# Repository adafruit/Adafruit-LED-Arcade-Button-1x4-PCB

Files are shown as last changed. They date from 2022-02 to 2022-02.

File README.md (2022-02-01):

## Adafruit LED Arcade Button 1x4 - STEMMA QT I2C Breakout PCB

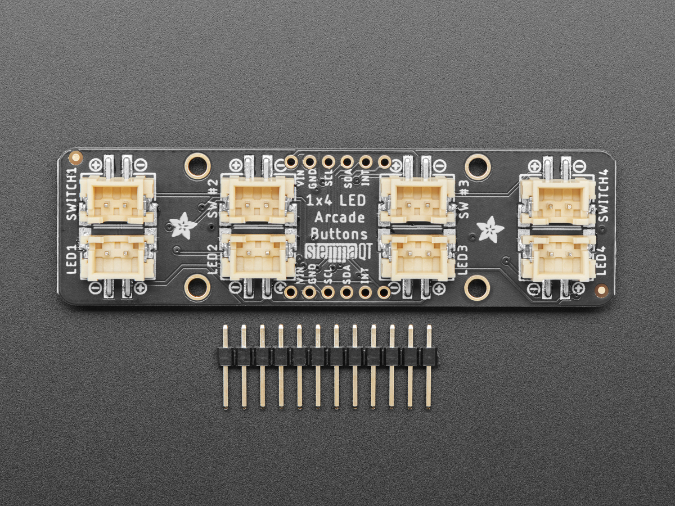
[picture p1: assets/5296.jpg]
<a href="http://www.adafruit.com/products/5296"><br/>
Click here to purchase one from the Adafruit shop</a>

PCB files for the Adafruit LED Arcade Button 1x4 - STEMMA QT I2C Breakout

Format is EagleCAD schematic and board layout
* https://www.adafruit.com/product/5296

### Description

The only thing better than a glowy arcade button is, perhaps, FOUR glowing arcade buttons - and that's what the Adafruit LED Arcade Button 1x4 QT I2C Breakout will let you do! This long 3" x 0.8" PCB has 8 x JST XH sockets that will fit our arcade button quick connects. Each XH pair lets you connect one arcade button that has a built in LED illuminator, and makes it easy to use with a breadboard/perfboard or with a STEMMA QT (Qwiic) connector for instant I2C connectivity on any platform.

### License

Adafruit invests time and resources providing this open source design, please support Adafruit and open-source hardware by purchasing products from [Adafruit](https://www.adafruit.com)!

Designed by Limor Fried/Ladyada for Adafruit Industries.

Creative Commons Attribution/Share-Alike, all text above must be included in any redistribution. 
See license.txt for additional details.

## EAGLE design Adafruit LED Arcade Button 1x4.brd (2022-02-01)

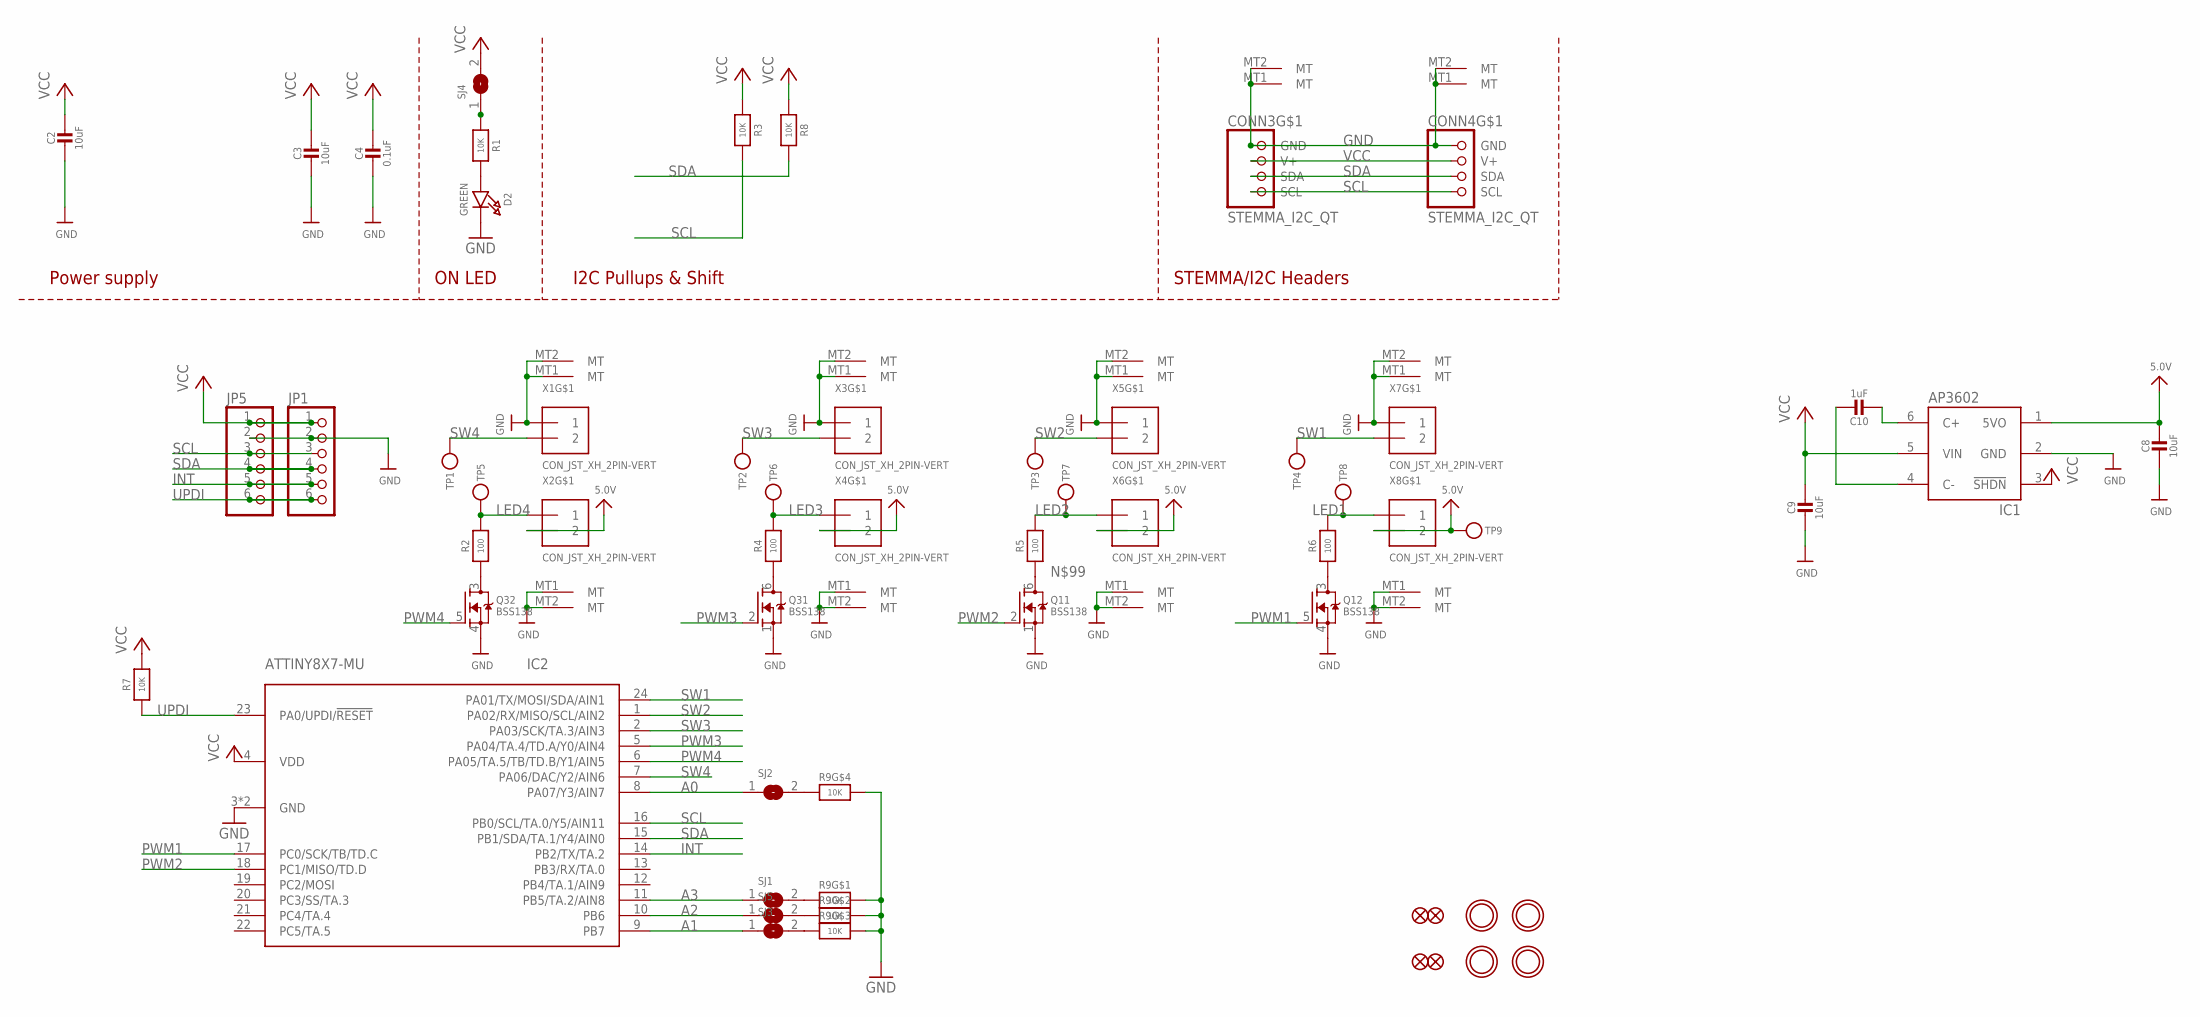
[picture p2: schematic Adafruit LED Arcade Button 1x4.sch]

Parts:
C2, C3, C8, C9: 10uF; 0805-NO
C4: 0.1uF; 0603-NO
C10: 1uF; 0805-NO
CONN3, CONN4: STEMMA_I2C_QT; JST_SH4
D2: GREEN; CHIPLED_0603_NOOUTLINE
FID1, FID2, FID3, FID4: FIDUCIAL_1MM
IC1: AP3602; SOT23-6
IC2: ATTINY8X7-MU; QFN24_4MM
JP1, JP5: HEADER-1X670MIL; 1X06_ROUND_70
Q1, Q3: BSS138; SOT363
R1, R3, R7, R8: 10K; 0603-NO
R2, R4, R5, R6: 100; 0603-NO
R9: 10K; RESPACK_4X0603
SJ1, SJ2, SJ3, SJ4, SJ5: SOLDERJUMPERCLOSED; SOLDERJUMPER_CLOSEDWIRE
TP1, TP2, TP3, TP4, TP5, TP6, TP7, TP8, TP9: TESTPOINTROUND1.5MM; TESTPOINT_ROUND_1.5MM
U$3, U$17, U$19, U$21: MOUNTINGHOLE2.5; MOUNTINGHOLE_2.5_PLATED
X1, X2, X3, X4, X5, X6, X7, X8: CON_JST_XH_2PIN-VERT; JST-XH-2-SV

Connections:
5.0V: C8.1, IC1.1 (5VO), TP9.P$1, X2.2, X4.2, X6.2, X8.2
A0: IC2.8 (PA07/Y3/AIN7), SJ2.1
A1: IC2.9 (PB7), SJ3.1
A2: IC2.10 (PB6), SJ5.1
A3: IC2.11 (PB5/TA.2/AIN8), SJ1.1
GND: C2.2, C3.2, C4.2, C8.2, C9.2, CONN3.1 (GND), CONN3.MT1 (MT), CONN3.MT2 (MT), CONN4.1 (GND), CONN4.MT1 (MT), CONN4.MT2 (MT), D2.C, IC1.2 (GND), IC2.3 (GND), IC2.THERM (GND), JP1.2, JP5.2, Q1.1 (S), Q1.4 (S), Q3.1 (S), Q3.4 (S), R9.5 (2), R9.6 (2), R9.7 (2), R9.8 (2), X1.1, X1.MT1 (MT), X1.MT2 (MT), X2.MT1 (MT), X2.MT2 (MT), X3.1, X3.MT1 (MT), X3.MT2 (MT), X4.MT1 (MT), X4.MT2 (MT), X5.1, X5.MT1 (MT), X5.MT2 (MT), X6.MT1 (MT), X6.MT2 (MT), X7.1, X7.MT1 (MT), X7.MT2 (MT), X8.MT1 (MT), X8.MT2 (MT)
INT: IC2.14 (PB2/TX/TA.2), JP1.5, JP5.5
LED1: R6.2, TP8.P$1, X8.1
LED2: R5.2, TP7.P$1, X6.1
LED3: R4.2, TP6.P$1, X4.1
LED4: R2.2, TP5.P$1, X2.1
unnamed: D2.A, R1.2
unnamed: C10.2, IC1.6 (C+)
unnamed: C10.1, IC1.4 (C-)
unnamed: Q3.6 (D), R4.1
unnamed: R1.1, SJ4.1
unnamed: R9.1, SJ1.2
unnamed: R9.2 (1), SJ5.2
unnamed: R9.3 (1), SJ3.2
unnamed: Q1.3 (D), R6.1
unnamed: Q3.3 (D), R2.1
unnamed: R9.4 (1), SJ2.2
unnamed: Q1.6 (D), R5.1
PWM1: IC2.17 (PC0/SCK/TB/TD.C), Q1.5 (G)
PWM2: IC2.18 (PC1/MISO/TD.D), Q1.2 (G)
PWM3: IC2.5 (PA04/TA.4/TD.A/Y0/AIN4), Q3.2 (G)
PWM4: IC2.6 (PA05/TA.5/TB/TD.B/Y1/AIN5), Q3.5 (G)
SCL: CONN3.4 (SCL), CONN4.4 (SCL), IC2.16 (PB0/SCL/TA.0/Y5/AIN11), JP1.3, JP5.3, R3.2
SDA: CONN3.3 (SDA), CONN4.3 (SDA), IC2.15 (PB1/SDA/TA.1/Y4/AIN0), JP1.4, JP5.4, R8.2
SW1: IC2.24 (PA01/TX/MOSI/SDA/AIN1), TP4.P$1, X7.2
SW2: IC2.1 (PA02/RX/MISO/SCL/AIN2), TP3.P$1, X5.2
SW3: IC2.2 (PA03/SCK/TA.3/AIN3), TP2.P$1, X3.2
SW4: IC2.7 (PA06/DAC/Y2/AIN6), TP1.P$1, X1.2
UPDI: IC2.23 (PA0/UPDI/!RESET), JP1.6, JP5.6, R7.1
VCC: C2.1, C3.1, C4.1, C9.1, CONN3.2 (V+), CONN4.2 (V+), IC1.3 (!SHDN), IC1.5 (VIN), IC2.4 (VDD), JP1.1, JP5.1, R3.1, R7.2, R8.1, SJ4.2

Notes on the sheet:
I2C Pullups & Shift
STEMMA/I2C Headers
ON LED
Power supply

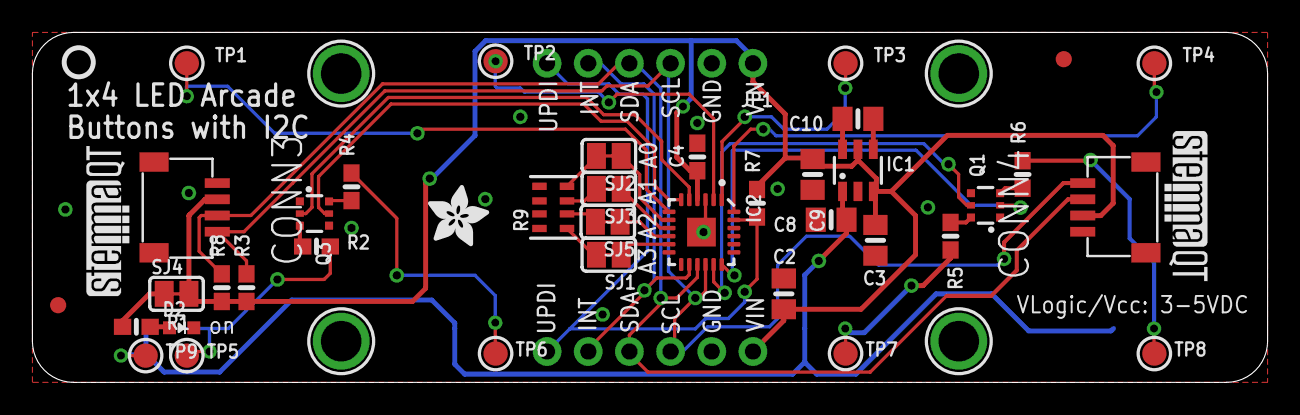
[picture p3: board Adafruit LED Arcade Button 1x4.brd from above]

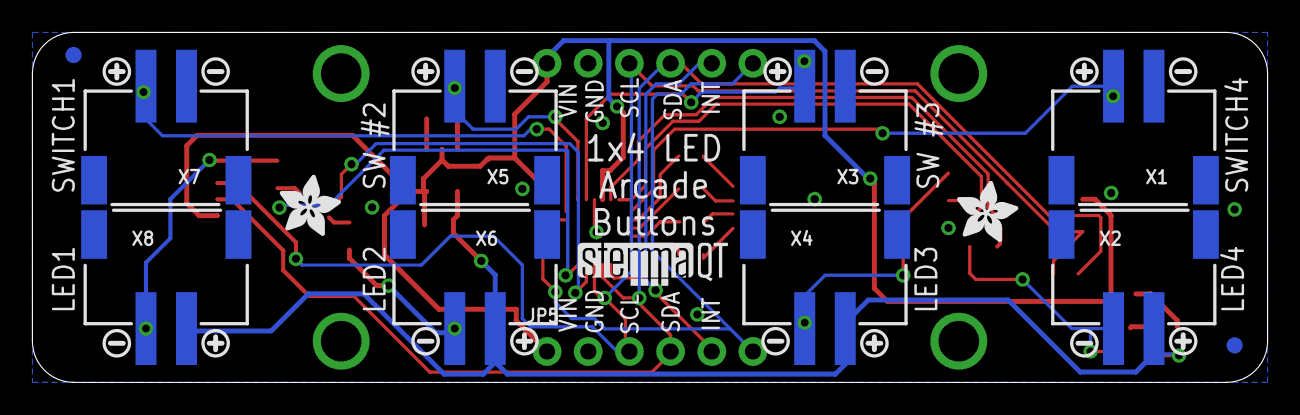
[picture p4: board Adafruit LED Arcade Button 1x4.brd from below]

Board: 2 copper layers, 76.2 x 21.6 mm, 77 parts (30 on the bottom side), 35 nets.

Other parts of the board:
U$1, U$8, U$14, U$45, U$46, U$47, U$48, U$49: SYMBOL_MINUS
U$2, U$9, U$52: ADAFRUIT_3.5MM
U$7, U$15, U$16, U$20, U$23, U$24, U$26, U$50: SYMBOL_PLUS
U$25: PCBFEAT-REV-040
U$30, U$31, U$53: STEMMAQT

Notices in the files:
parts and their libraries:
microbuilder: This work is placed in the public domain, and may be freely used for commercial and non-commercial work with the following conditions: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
